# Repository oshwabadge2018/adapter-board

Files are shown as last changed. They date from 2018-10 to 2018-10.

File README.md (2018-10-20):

## Adapter board for USB-to-serial cable
adapter board to connect USB-to-serial cable to J1 header on Open Hardware Summit badge

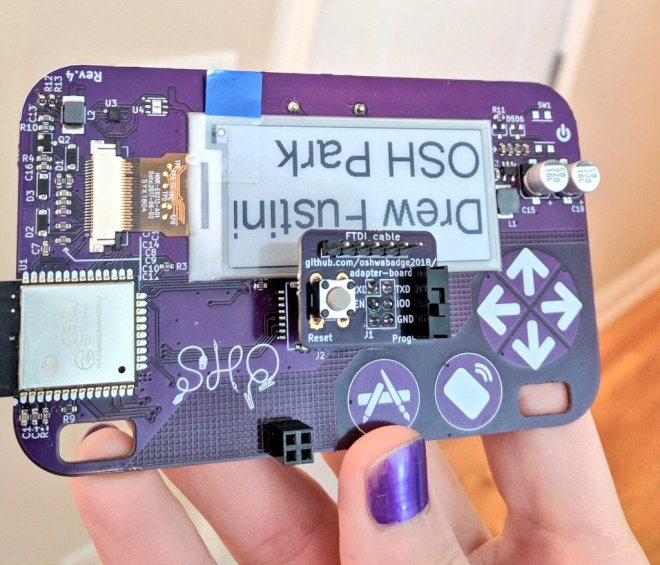
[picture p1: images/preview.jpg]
(http://blog.oshpark.com/2018/10/19/adapter-board-for-open-hardware-summit-badge/)


### [OSH Park shared project](https://oshpark.com/shared_projects/39CXLX65)
Order the PCB from OSH Park:

[Adapter board for USB-to-serial cable](https://oshpark.com/shared_projects/39CXLX65)

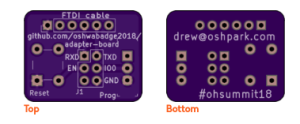
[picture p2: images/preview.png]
OSH Park PCB preview (https://oshpark.com/shared_projects/39CXLX65)


order from OSH Park (https://oshpark.com/shared_projects/39CXLX65)

### [Blog post](http://blog.oshpark.com/2018/10/19/adapter-board-for-open-hardware-summit-badge/)
[Adapter board for Open Hardware Summit badge](http://blog.oshpark.com/2018/10/19/adapter-board-for-open-hardware-summit-badge/)
> The badge features an ESP32 microcontroller running MicroPython firmware.  The firmware provides a Python interpreter prompt (REPL) on the serial port which allows interactive programming of the badge!
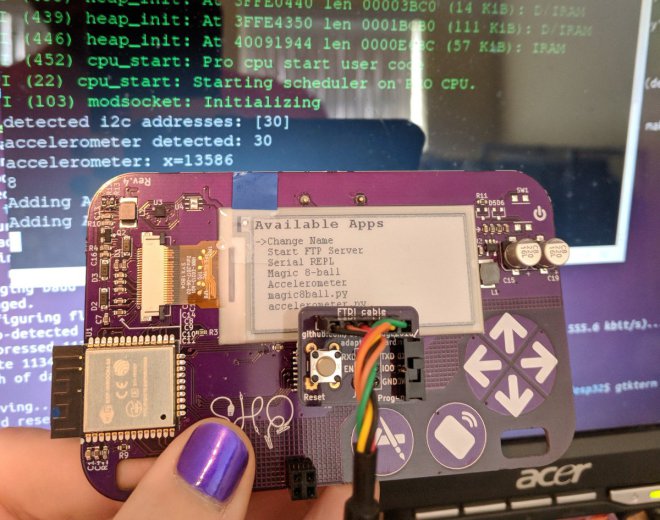
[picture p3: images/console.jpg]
(http://blog.oshpark.com/2018/10/19/adapter-board-for-open-hardware-summit-badge/)


### Bill of Materials (BoM)
* **[Digi-Key shopping cart](https://www.digikey.com/short/jdb477)**

* Switch for programming mode
  * E-Switch EG1218
  * Slide Switch SPDT
  * Digi-Key: [EG1903-ND](https://www.digikey.com/short/jdmjh3)

* Pushbutton for reset
  * Omron B3F-1000
  * Tactile Switch SPST-NO
  * Digi-Key: [SW400-ND](https://www.digikey.com/short/jdmjhz)

* Header for FTDI usb-to-serial cable
  * TE AMP 9-146282-0-06
  * 1x6 Pin Header 0.1" pitch
  * Digi-Key: [A34253-06-ND](https://www.digikey.com/short/jdmjhd)

* Header to connect J1 socket on badge
  * Harwin M20-9720345
  * 2x3 Pin Header 0.1" pitch
  * Digi-Key: [952-1921-ND](https://www.digikey.com/short/jdmj9p)
  
* J1 header socket on the badge
  * Harwin 952-1781-ND
  * 2x3 Header Socket  0.1" pitch
  * Digi-Key: [M20-7830346](https://www.digikey.com/short/jdbtfc)

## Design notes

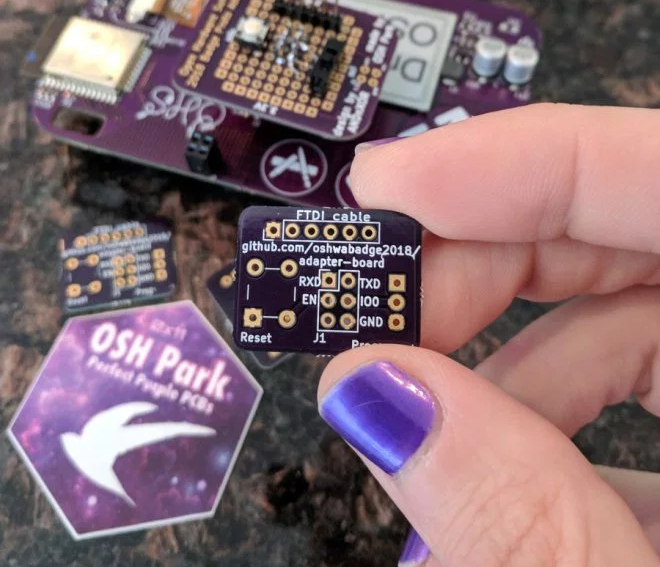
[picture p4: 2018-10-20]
images/board.png

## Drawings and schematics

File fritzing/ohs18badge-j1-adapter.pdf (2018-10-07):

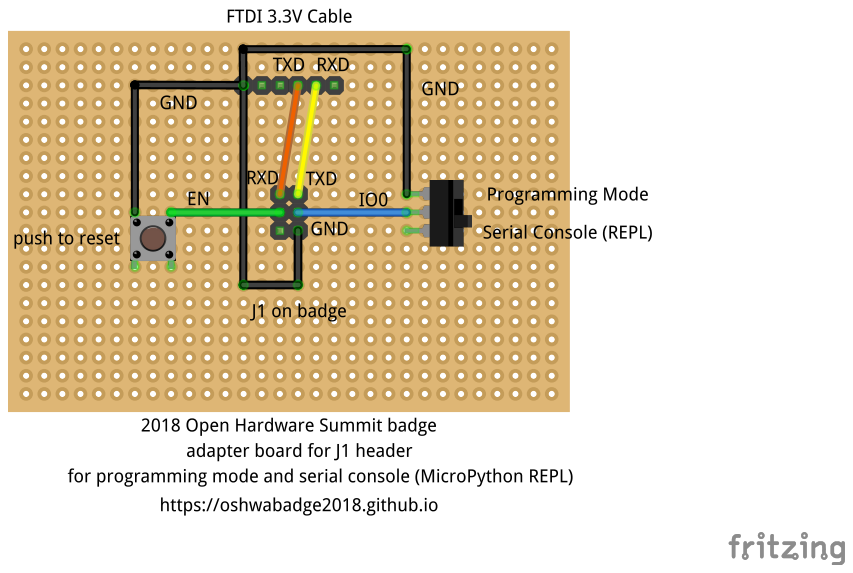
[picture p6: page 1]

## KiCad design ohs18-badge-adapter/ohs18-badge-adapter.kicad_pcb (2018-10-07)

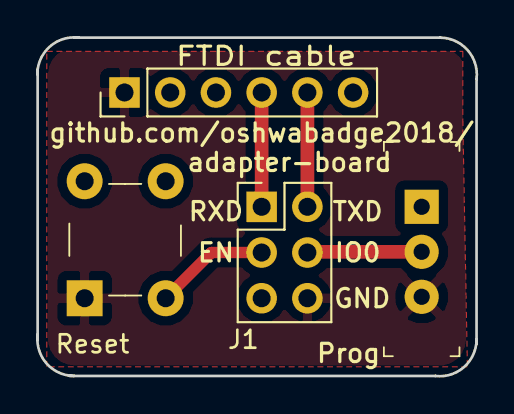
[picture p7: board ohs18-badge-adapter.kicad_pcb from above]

Board: 2 copper layers, 24.4 x 18.8 mm, 4 parts (0 on the bottom side), 5 nets.

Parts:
J1: OHS18 Badge; PinHeader_2x03_P2.54mm_Vertical
J2: FTDI 3.3V USB to Serial; PinHeader_1x06_P2.54mm_Vertical
Mode1: EG1218; Switch_Slide_11.6x4mm_EG1218
Reset: B3F-1000; Switch_Tactile_THT_B3F-1xxx

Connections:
EN: J1.3, Reset.3
GND: J1.6, J2.1, Mode1.3, Reset.1
IO0: J1.4, Mode1.2
RXD: J1.2, J2.5
TXD: J1.1, J2.4

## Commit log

2018-10-07 initial schematic
    [ohs18-badge-adapter.kicad_pcb, ohs18-badge-adapter.sch, ohs18badge-j1-adapter.fzz]
2018-10-07 finish layout of rev 1
    [ohs18-badge-adapter.kicad_pcb, ohs18-badge-adapter.sch]
